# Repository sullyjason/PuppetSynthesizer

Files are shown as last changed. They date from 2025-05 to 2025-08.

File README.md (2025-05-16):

# Puppet Synth

A collaborative project between ZHdK's Departments of Interaction Design and Game Design, commissioned by Museum für Gestaltung.

## Project brief

For the Exhibition "Museum of the Future" in 2025, Zürich's Museum für Gestaltung has commissioned ZHdK to develop a series of interactive installations paying tribute to Sophie Täuber Arp's infamous wooden marionettes that she created for the play _King Stag_.

### Team

The team consists of five members coming from various disciplines.

- Lisa Bach [@julielionheart](https://github.com/julielionheart) - Unity 3D and creative direction
- Silvan Roth [@sullyjason](https://github.com/sullyjason) - Interface design and hardware
- Jan Hügli - Prototyping and production
- Jan Thürig [@JanThuering](https://github.com/JanThuering) - Unity 3D and firmware
- Jan Espig [@Jespig](https://github.com/Jespig) - Visual design
- David Bock [@davidoffcw](https://github.com/davidoffcw) & Lars Kristian [@larskristianblom](https://github.com/larskristianblom) - Sound design

## Concept

Puppet Synth is a digital reinterpretation of Sophie Taeuber-Arp’s avant-garde puppetry for King Stag, breaking with traditional visual and performative conventions. Inspired by Rudolf Laban’s choreographic notation and Taeuber-Arp’s expressive dance practice, this project brings the puppets’ gestures into the digital realm. Users are invited to choreograph puppet movements themselves. Visually, Puppet Synth renders these complex motion sequences as wave-like frequency patterns, making them both tangible and analyzable.

## Implementation

```mermaid
flowchart TD
    Interface["🎛️ Physical Interface"] --> Arduino["Analog Signal processing"]
    Arduino --> MIDI["🎹 MIDI / Control Signal"]

    MIDI --> WaveSynthesis["Wave synthesis"] --> FMOD["🔊 FMOD (Audio Synthesis)"]
    WaveSynthesis --> UnityAnim["🕺 Unity Animator (Puppet Control)"]

    FMOD --> Audio["🎵 Dynamic Audio Output"]
    UnityAnim --> Visual["🎭 Puppet Animation in Unity"]

    Audio & Visual --> Output["🎬 Final Experience (Live AV Performance)"]
```
### Interface

The interface consists of 5 types of inputs: rotary switches, smooth rotary potentiometers, linear potentiometers (faders), and momentary 3 position toggle switches.
<p align="center">
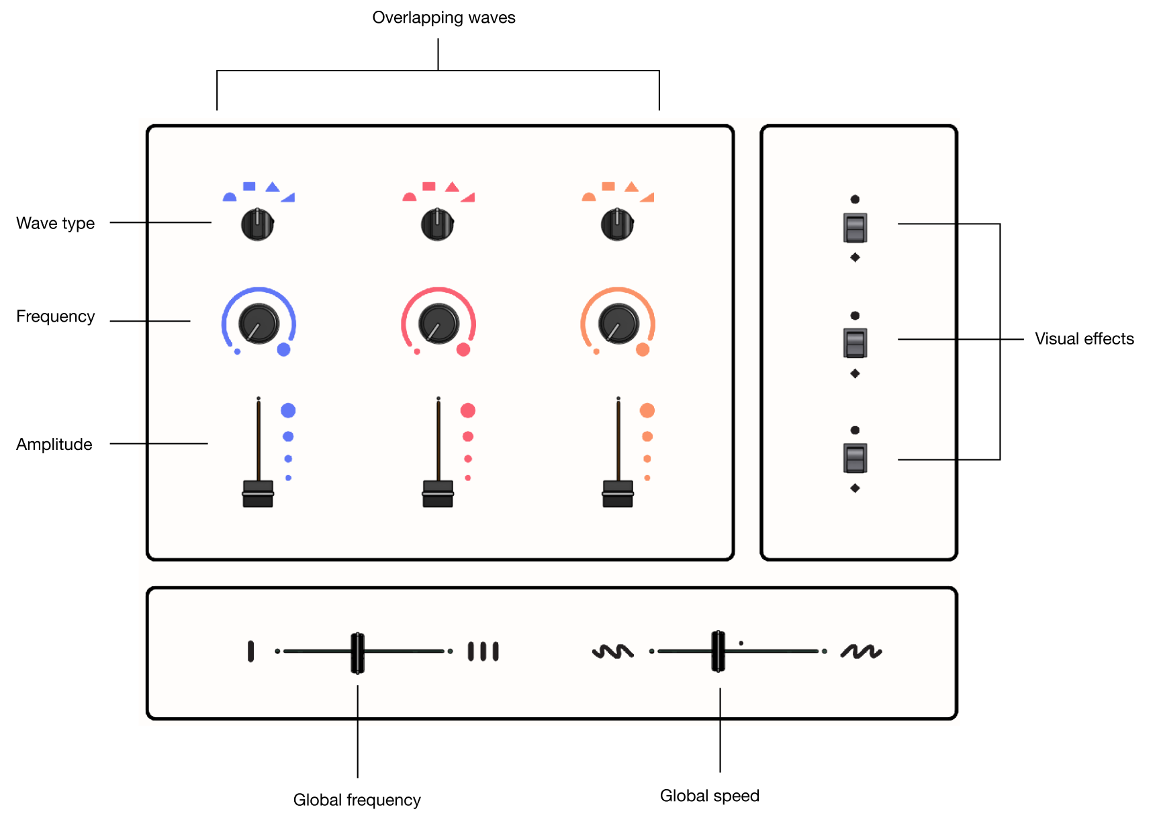
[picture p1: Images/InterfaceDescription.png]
Interface Diagram

</p>

### Visual Style

The visual style takes inspiration from Sophie Täuber-Arp's minimal color palette and simple revolved shapes that make up the marionettes.
<p align="center">
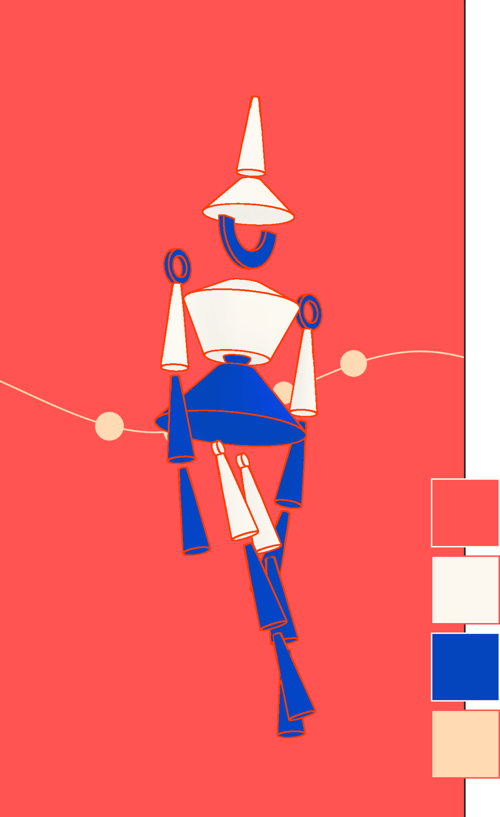
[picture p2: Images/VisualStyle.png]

</p>

## Experience

## Repository files

- Firmware (arduino code)
- Electronic Design files
- CAD drawings and STLs
- Unity build and project files
- FMOD code

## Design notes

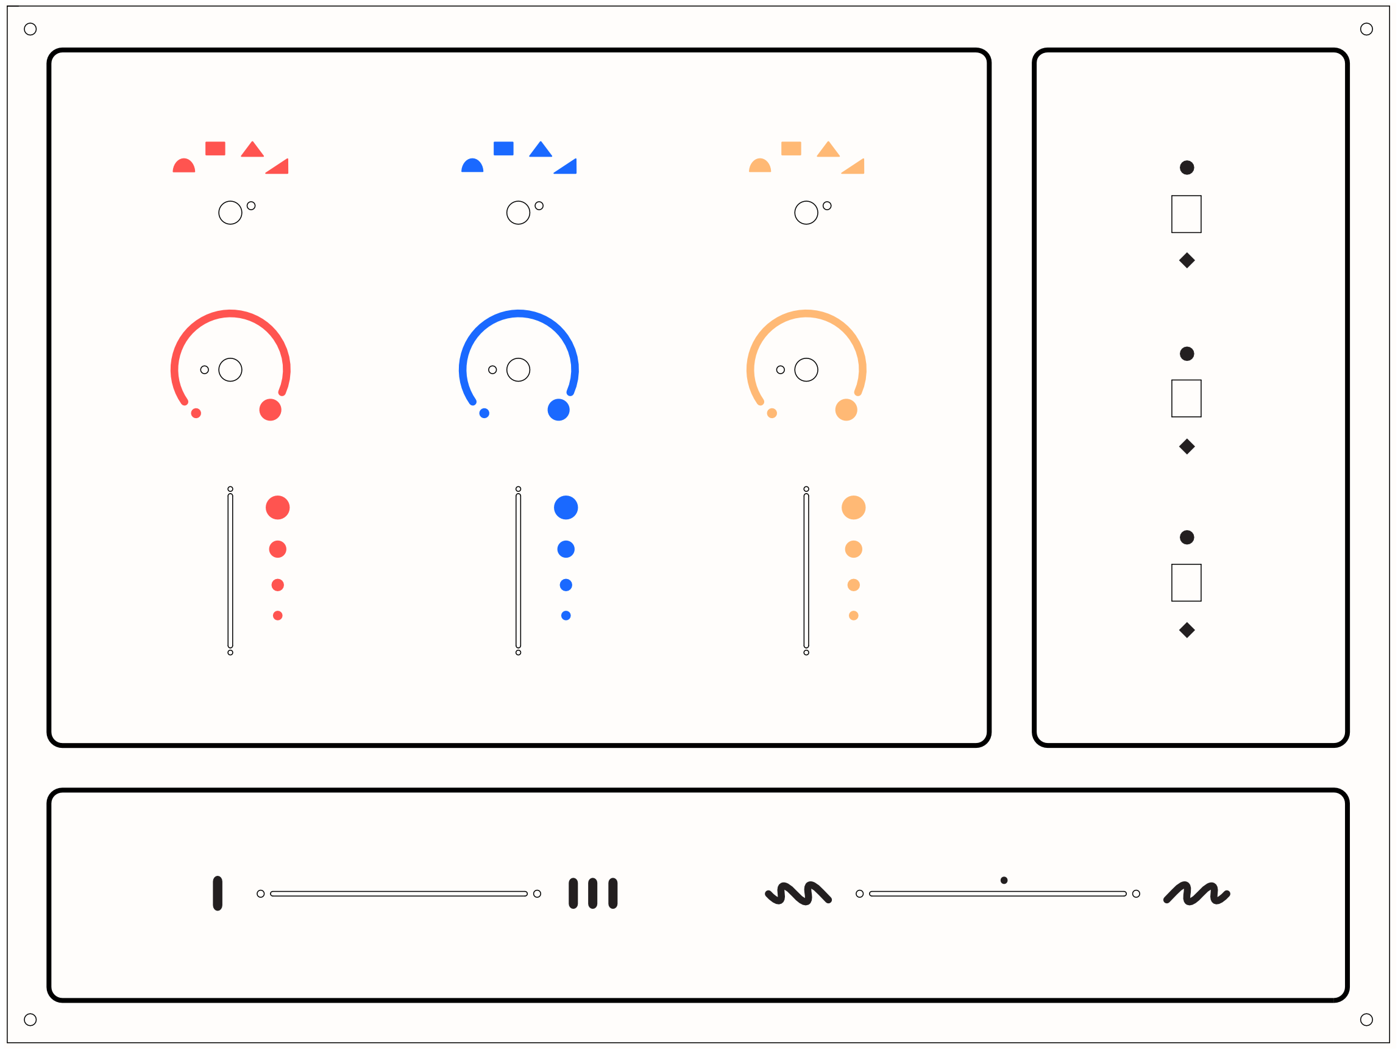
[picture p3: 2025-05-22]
Enclosure/Panel_Design.png

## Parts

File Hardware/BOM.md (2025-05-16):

# Bill of Materials (BOM)

| **Part** | **Qty** | **Link / Part Number** |
|---|---:|---|
| Rotary Switch | 3 | [DFRobot](https://www.dfrobot.com/product-970.html) |
| Linear Potentiometer 10k – 60mm travel  | 3 | [858-PS6020MC1BR10K – Mouser](https://www.mouser.ch/ProductDetail/858-PS6020MC1BR10K) |
| Linear Potentiometer 10k – 100mm travel | 2 | [858-PS1001B1BR10K – Mouser](https://www.mouser.ch/ProductDetail/858-PS1001B1BR10K) |
| Rotary Potentiometer 10k | 3 | [858-P2301FD20BR10K – Mouser](https://www.mouser.ch/ProductDetail/858-P2301FD20BR10K) |
| 3-position Rocker Switch | 3 | [506-A105J61ZQ0004 – Mouser](https://www.mouser.ch/ProductDetail/506-A105J61ZQ0004) |
| ADS1115 16-bit ADC (4-Channel) | 2 | [Adafruit #1085](https://www.adafruit.com/product/1085) |
| 2.2kΩ THT Resistor | 6 | — |
| 100Ω THT Resistor | 3 | — |
| 4.7kΩ THT Resistor | 2 | — |
| 1µF Ceramic Capacitor (THT) | 3 | — |
| Arduino Leonardo | 1 | [Arduino Docs](https://docs.arduino.cc/hardware/leonardo/) |
| Micro USB Cable – 2m | 1 | — |
| JST 2.50mm Vertical 3-pin Socket | 11 | — |
| JST 2.50mm Vertical 5-pin Socket | 6 | — |
| JST 3-pin Cable | 11 | — |
| JST 5-pin Cable | 3 | — |
| Countersunk screw M2x6 | 6 | — |
| Countersunk screw M3x6 | 4 | — |
| Countersunk screw M5x10 | 4 | — |

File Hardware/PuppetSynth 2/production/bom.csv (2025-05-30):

Designator | Footprint | Quantity | Value | LCSC Part #
10K_2 | PS6020MC1BR10K | 1 | R_Potentiometer
10K | PS1001B1BR10K | 1 | R_Potentiometer
A1 | Arduino_UNO_R3 | 1 | Arduino_Leonardo
C3, C4, C5 | C_Disc_D3.0mm_W2.0mm_P2.50mm | 3 | 1uF
H1, H13, H2, H3, H4 | MountingHole_3.2mm_M3 | 5 | MountingHole_M3
J10, J19, J8, J9 | PinSocket_1x06_P2.54mm_Vertical | 4 | PINHD_1x6_Female
J11, J12, J16, J20, J24, J25, J26, J3 | JST_EH_B3B-EH-A_1x03_P2.50mm_Vertical | 8 | JST_03
J13, J14, J15, J5 | JST_EH_B5B-EH-A_1x05_P2.50mm_Vertical | 4 | JST_05
JP1, JP2 | SolderJumper-2_P1.3mm_Open_RoundedPad1.0x1.5mm | 2 | Jumper_2_Bridged
R1, R2 | R_Axial_DIN0207_L6.3mm_D2.5mm_P10.16mm_Horizontal | 2 | 4.7k
R10, R11, R13, R14, R4, R5 | R_Axial_DIN0207_L6.3mm_D2.5mm_P10.16mm_Horizontal | 6 | 2.2k
R12, R17, R9 | R_Axial_DIN0207_L6.3mm_D2.5mm_P10.16mm_Horizontal | 3 | 100ohm

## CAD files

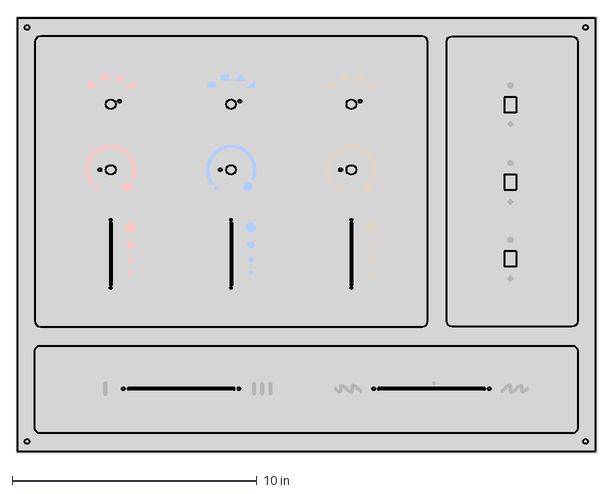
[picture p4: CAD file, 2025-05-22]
Enclosure/Panel_Design.dxf
23.8 x 17.9 in

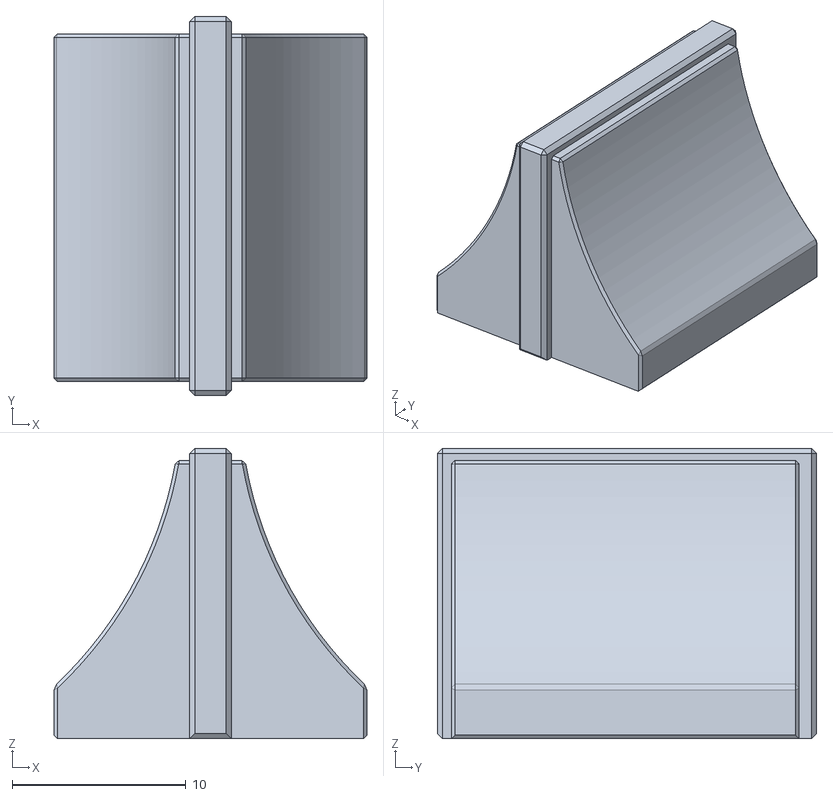
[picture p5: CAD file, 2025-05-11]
Hardware/Components/Caps/small faders.stl
18.0 x 21.8 x 16.7

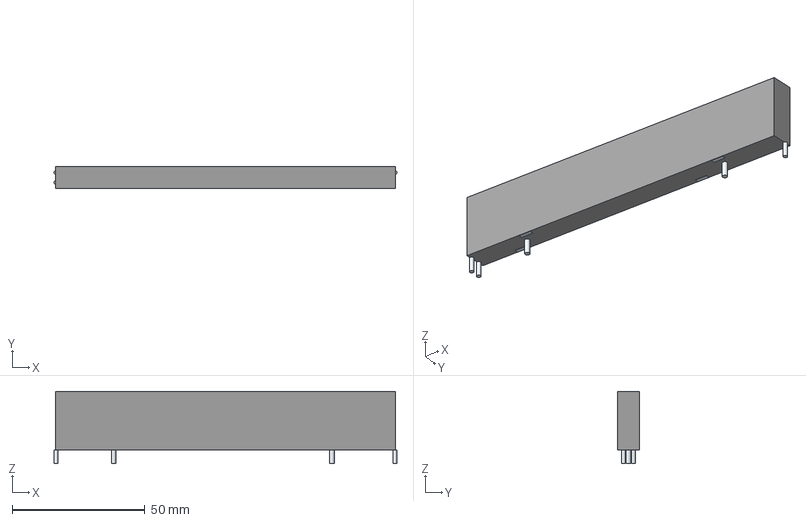
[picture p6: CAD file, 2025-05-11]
Hardware/Components/Fader_Long/PS100-1B1BR10K.stp
129.1 x 8.40 x 27.1 mm
Pins
Leads

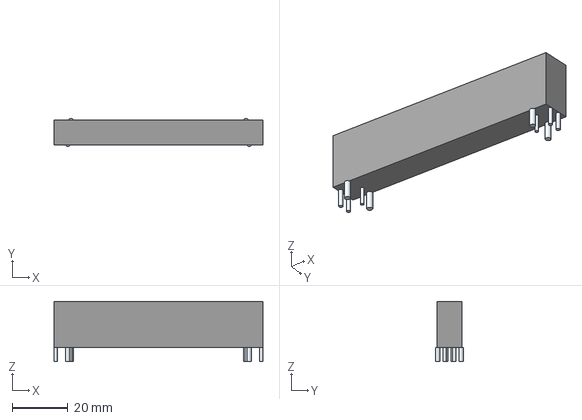
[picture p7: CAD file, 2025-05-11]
Hardware/Components/Fader_Short/PS60-20MC1BR10K.stp
75.0 x 10.2 x 21.6 mm
Leads x 10

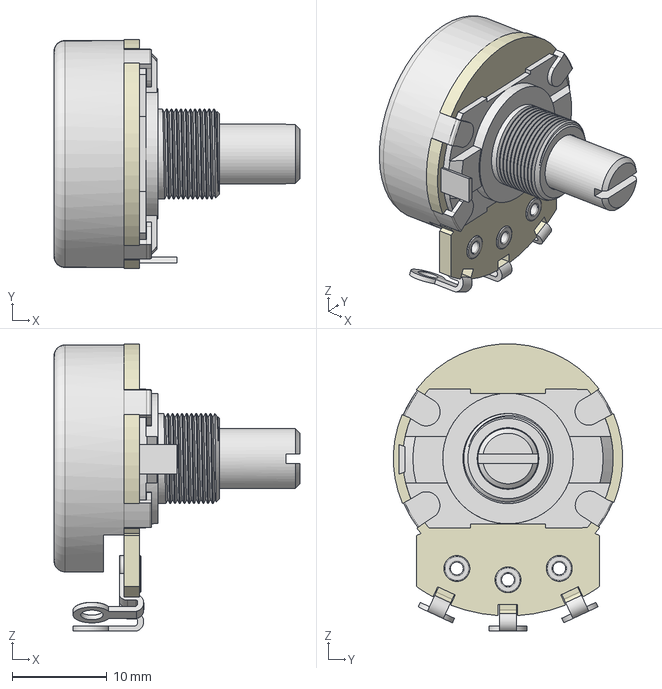
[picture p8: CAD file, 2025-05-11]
Hardware/Components/Potentiometer/P230-1EC15AR1MEG.stp
26.0 x 24.2 x 30.3 mm

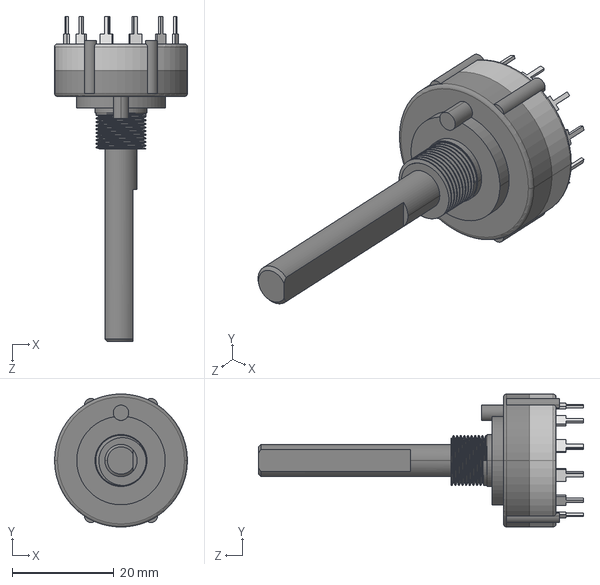
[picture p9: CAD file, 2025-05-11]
Hardware/Components/Rotary_Switch/CK1056.stp
26.2 x 26.2 x 64.1 mm

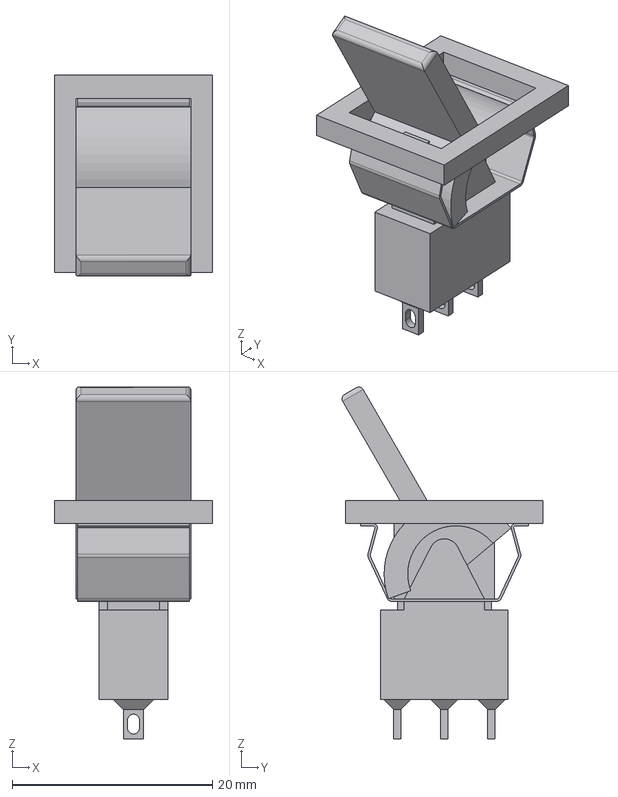
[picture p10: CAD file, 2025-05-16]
Hardware/Components/Toggle/A105J61ZQ0004.stp
15.8 x 20.1 x 35.1 mm

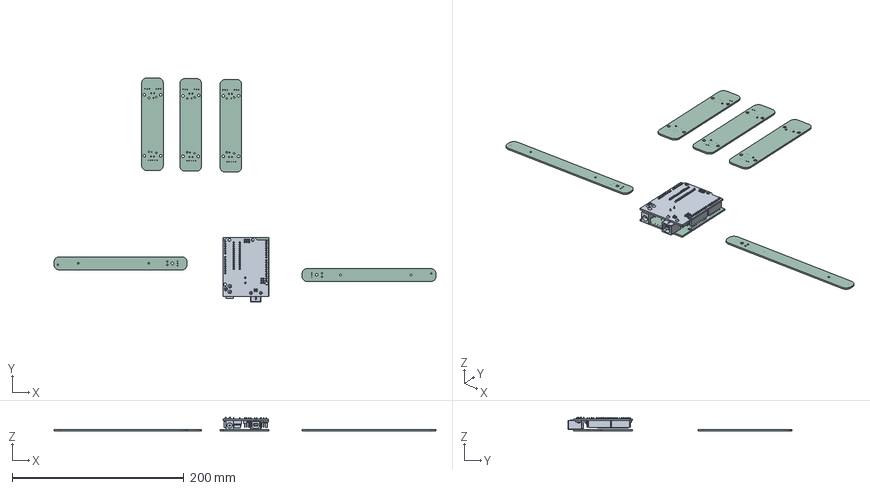
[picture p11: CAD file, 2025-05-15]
Hardware/PuppetSynth 2/PuppetSynth_v2_PCB.step
445.2 x 261.3 x 16.5 mm
ARDUINO-UNO
_autosave-PuppetSynth_v2_PCB_PCB_1
_autosave-PuppetSynth_v2_PCB_PCB_2
_autosave-PuppetSynth_v2_PCB_PCB_3
_autosave-PuppetSynth_v2_PCB_PCB_4
_autosave-PuppetSynth_v2_PCB_PCB_5
_autosave-PuppetSynth_v2_PCB_PCB_6
_autosave-PuppetSynth_v2_PCB_PCB_7
_autosave-PuppetSynth_v2_PCB_PCB_8
_autosave-PuppetSynth_v2_PCB_PCB_9
_autosave-PuppetSynth_v2_PCB_PCB_10
_autosave-PuppetSynth_v2_PCB_PCB_11
_autosave-PuppetSynth_v2_PCB_PCB_12
_autosave-PuppetSynth_v2_PCB_PCB_13
_autosave-PuppetSynth_v2_PCB_PCB_14
_autosave-PuppetSynth_v2_PCB_PCB_15
_autosave-PuppetSynth_v2_PCB_PCB_16
_autosave-PuppetSynth_v2_PCB_PCB_17
_autosave-PuppetSynth_v2_PCB_PCB_18
_autosave-PuppetSynth_v2_PCB_PCB_19
_autosave-PuppetSynth_v2_PCB_PCB_20
_autosave-PuppetSynth_v2_PCB_PCB_21
_autosave-PuppetSynth_v2_PCB_PCB_22
_autosave-PuppetSynth_v2_PCB_PCB_23
_autosave-PuppetSynth_v2_PCB_PCB_24
_autosave-PuppetSynth_v2_PCB_PCB_25
_autosave-PuppetSynth_v2_PCB_PCB_26
_autosave-PuppetSynth_v2_PCB_PCB_27
_autosave-PuppetSynth_v2_PCB_PCB_28
_autosave-PuppetSynth_v2_PCB_PCB_29
_autosave-PuppetSynth_v2_PCB_PCB_30
_autosave-PuppetSynth_v2_PCB_PCB_31
_autosave-PuppetSynth_v2_PCB_PCB_32
_autosave-PuppetSynth_v2_PCB_PCB_33
_autosave-PuppetSynth_v2_PCB_PCB_34
_autosave-PuppetSynth_v2_PCB_PCB_35
_autosave-PuppetSynth_v2_PCB_PCB_36

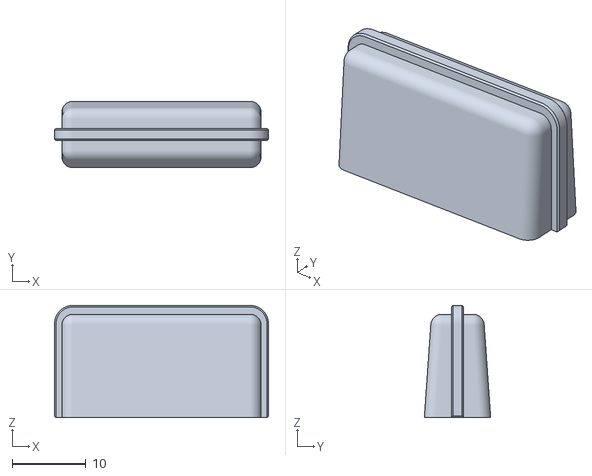
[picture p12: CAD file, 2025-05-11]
Hardware/Components/Caps/Large faders.stl
29.0 x 9.00 x 15.2

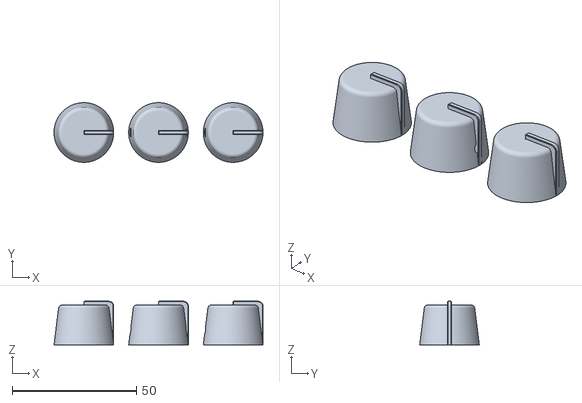
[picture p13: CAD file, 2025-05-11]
Hardware/Components/Caps/knobs.stl
84.0 x 24.0 x 17.5

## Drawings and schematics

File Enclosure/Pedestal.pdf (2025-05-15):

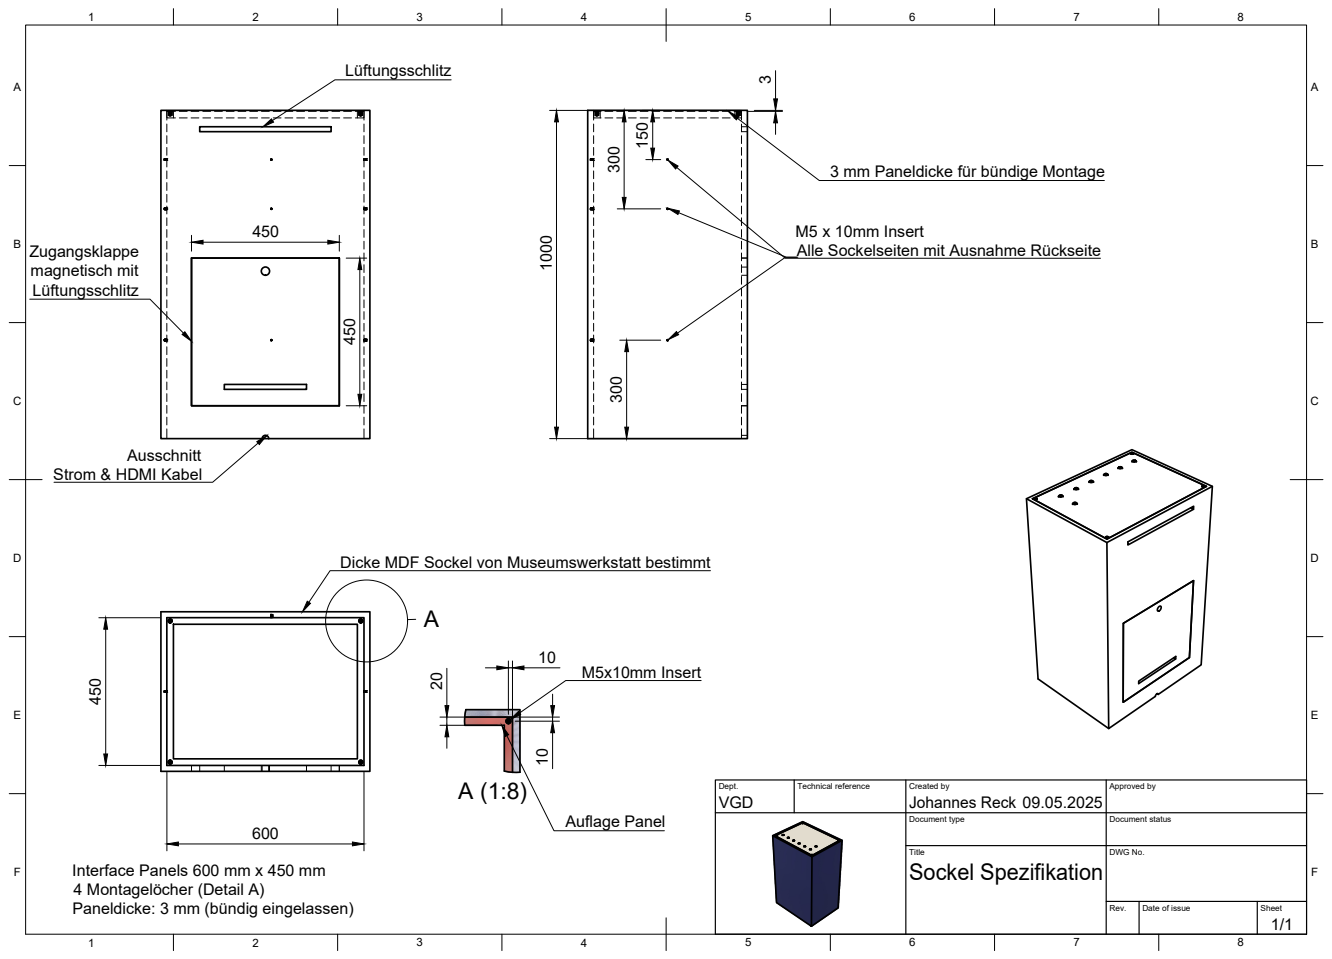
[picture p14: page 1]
Title; DWG No.; Rev.; Date of issue; Sheet; Sockel Spezifikation; M5x10mm Insert; M5 x 10mm Insert; magnetisch mit; Auflage Panel

Alle Sockelseiten mit Ausnahme Rückseite 150 300 300

3 mm Paneldicke für bündige Montage

Strom & HDMI Kabel

Dicke MDF Sockel von Museumswerkstatt bestimmt

Dept. VGD | Technical reference | Created by Johannes Reck 09.05.2025 | Approved by

Document type | Document status

Interface Panels 600 mm x 450 mm
4 Montagelöcher (Detail A)
Paneldicke: 3 mm (bündig eingelassen)

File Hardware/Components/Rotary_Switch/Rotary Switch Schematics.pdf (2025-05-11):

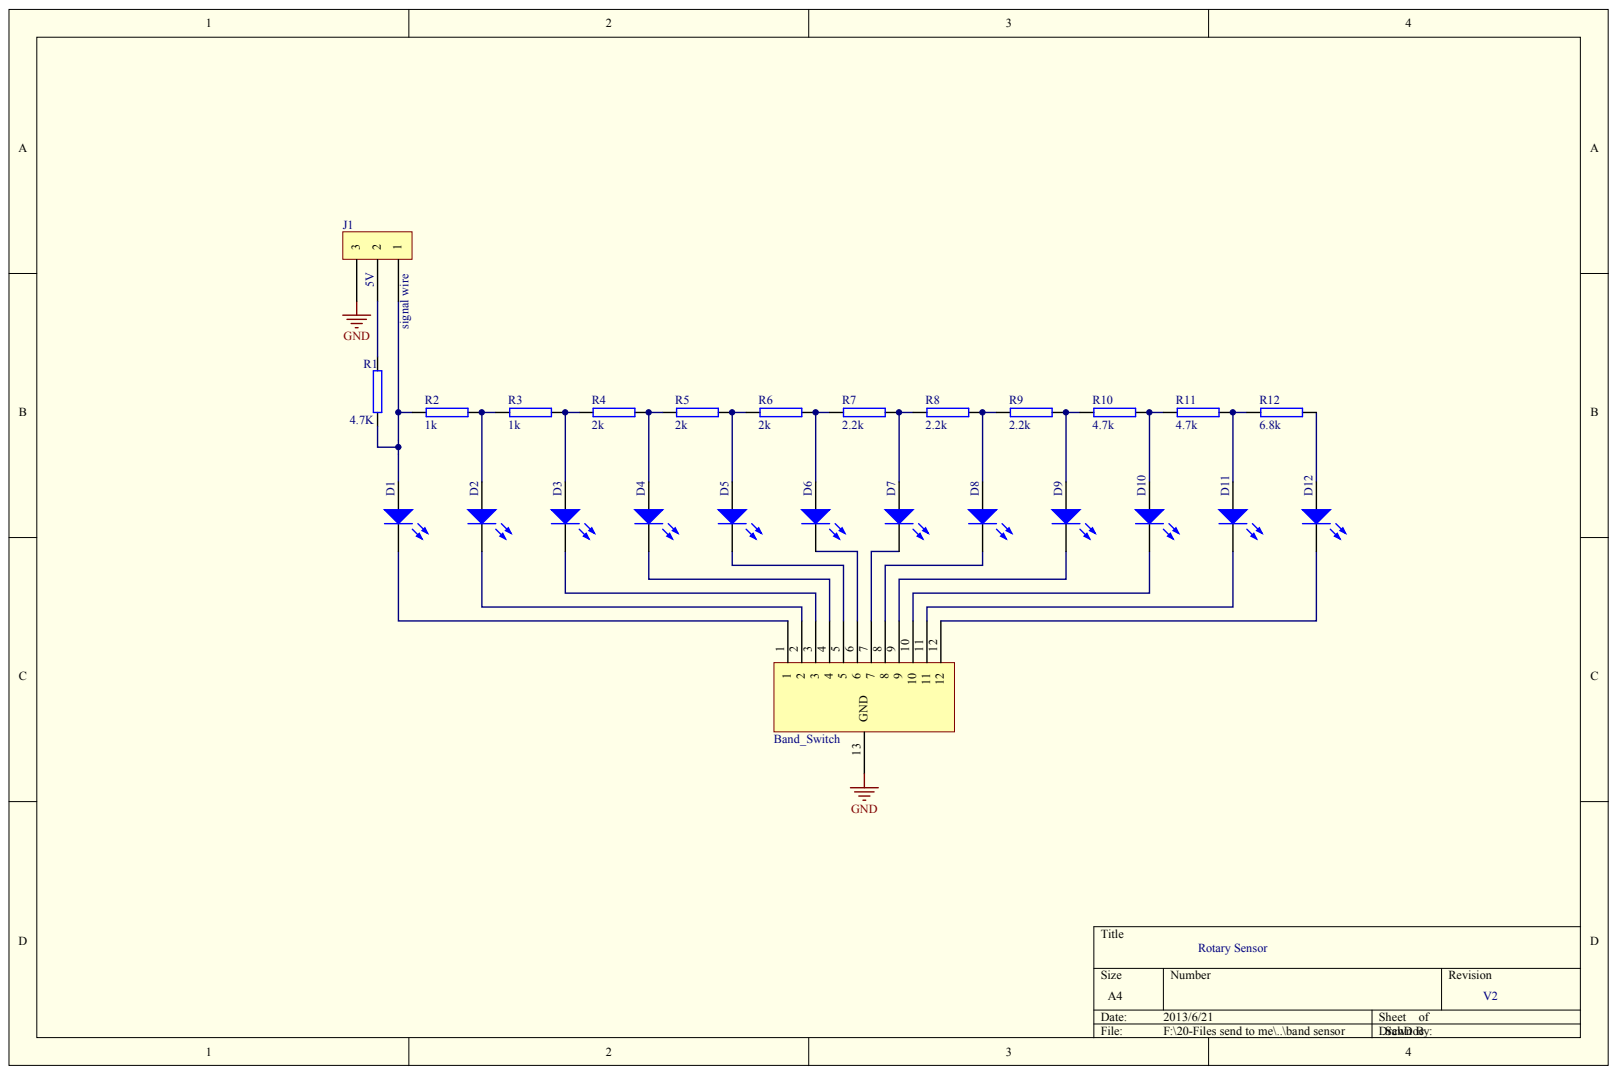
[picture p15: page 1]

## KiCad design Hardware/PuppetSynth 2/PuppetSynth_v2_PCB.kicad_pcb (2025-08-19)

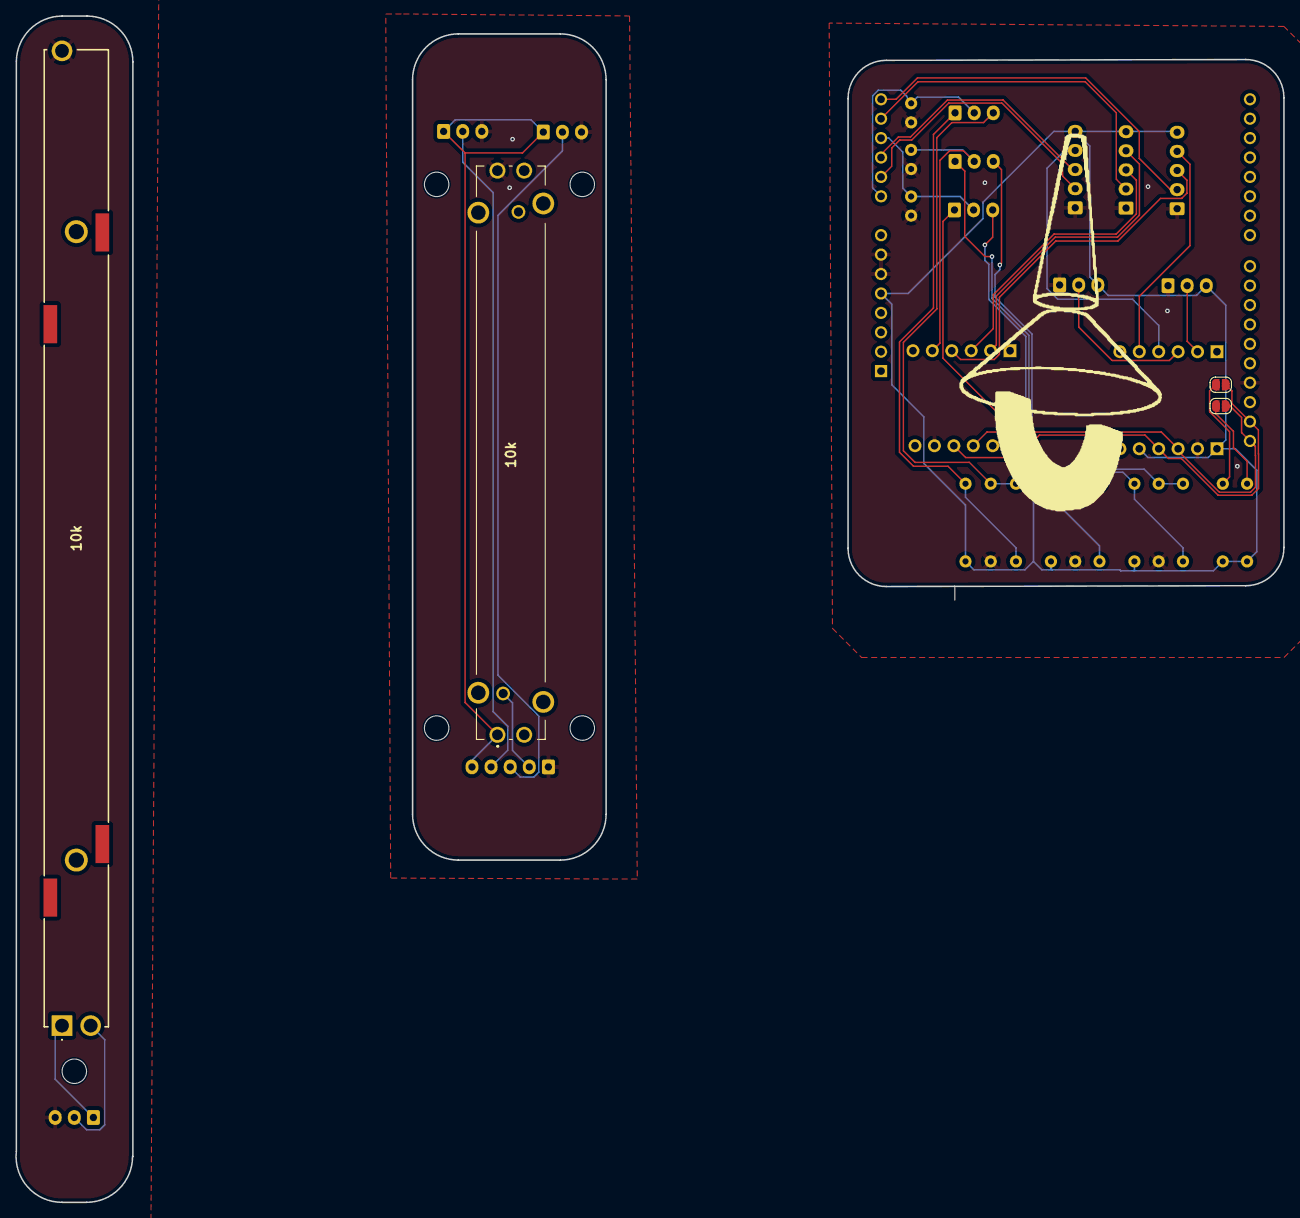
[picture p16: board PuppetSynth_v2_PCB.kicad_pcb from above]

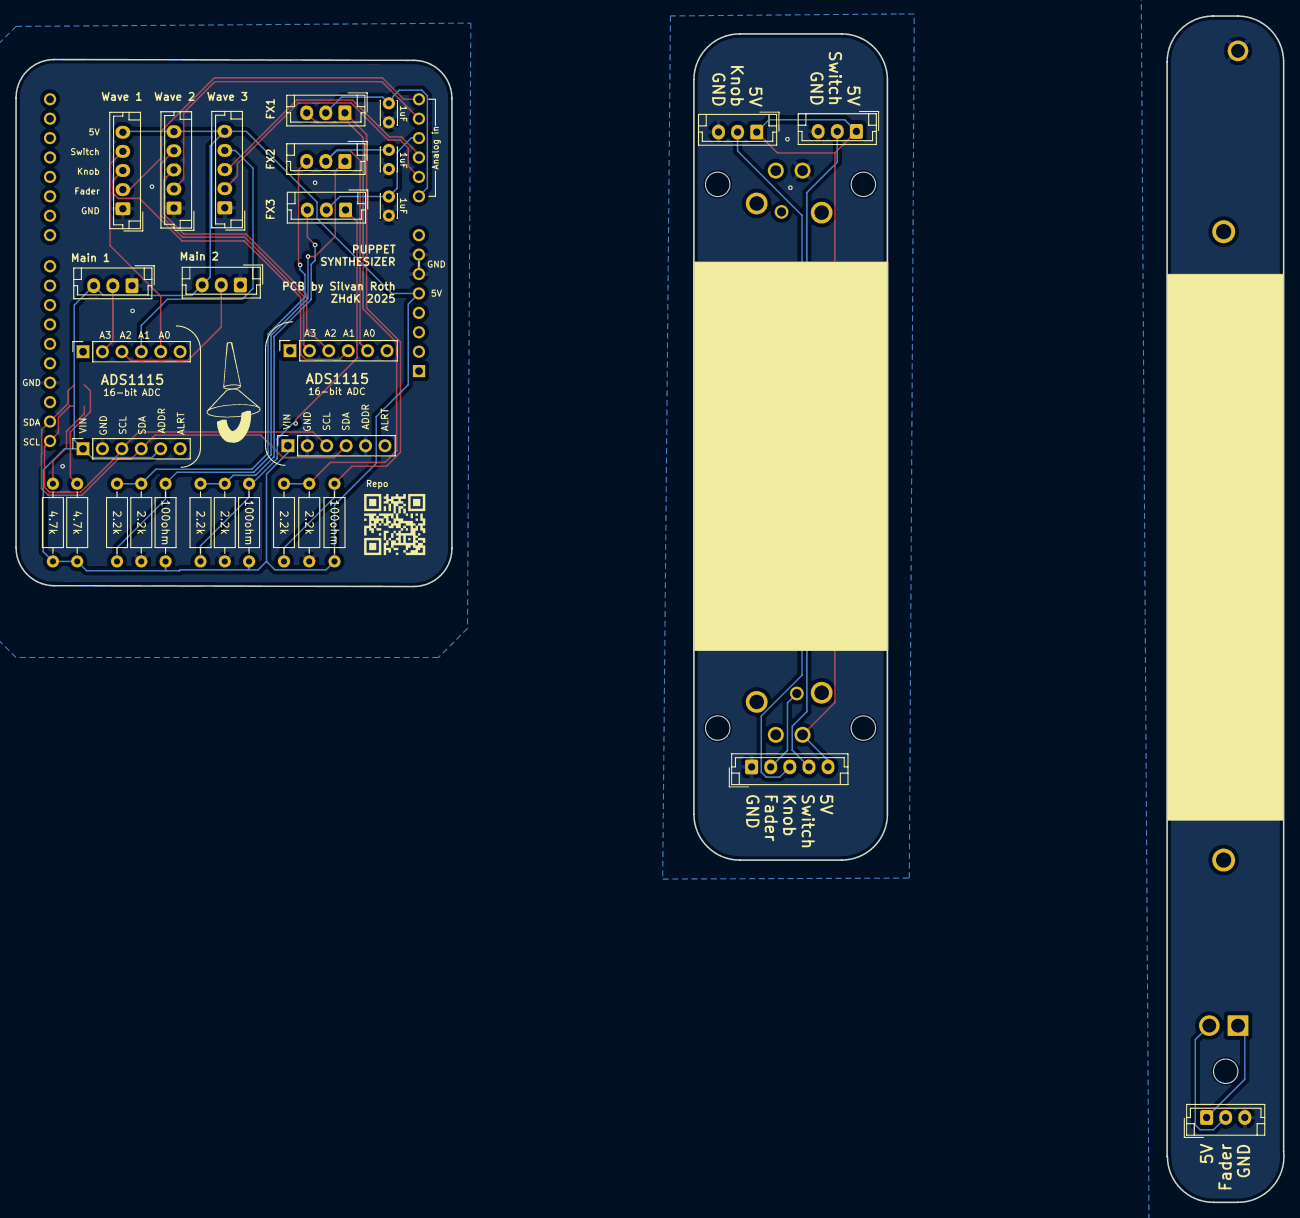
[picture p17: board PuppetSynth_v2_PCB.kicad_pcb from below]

Board: 2 copper layers, 57.0 x 68.9 mm, 40 parts (30 on the bottom side), 26 nets.

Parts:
10k: R_Potentiometer; PS6020MC1BR10K
10k#2: R_Potentiometer; PS1001B1BR10K
A1: Arduino_Leonardo; Arduino_UNO_R3
C3, C4, C5: 1uF; C_Disc_D3.0mm_W2.0mm_P2.50mm
H1, H2, H3, H4, H13: MountingHole_M3; MountingHole_3.2mm_M3
J3, J11, J12, J16, J20, J24, J25, J26: JST_03; JST_EH_B3B-EH-A_1x03_P2.50mm_Vertical
J5, J13, J14, J15: JST_05; JST_EH_B5B-EH-A_1x05_P2.50mm_Vertical
J8, J9, J10, J19: PINHD_1x6_Female; PinSocket_1x06_P2.54mm_Vertical
JP1, JP2: Jumper_2_Bridged; SolderJumper-2_P1.3mm_Open_RoundedPad1.0x1.5mm
R1, R2: 4.7k; R_Axial_DIN0207_L6.3mm_D2.5mm_P10.16mm_Horizontal
R4, R5, R10, R11, R13, R14: 2.2k; R_Axial_DIN0207_L6.3mm_D2.5mm_P10.16mm_Horizontal
R9, R12, R17: 100ohm; R_Axial_DIN0207_L6.3mm_D2.5mm_P10.16mm_Horizontal

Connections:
+5V: 10k.1, 10k#2.1, A1.5 (+5V), J3.1, J5.5, J8.1, J10.1, J10.5, J11.3, J12.3, J13.5, J14.5, J15.5, J16.1, J20.1, R1.2, R2.2, R9.2, R12.2, R17.2
GND: 10k.3, 10k#2.3, A1.6 (GND), A1.7 (GND), A1.29 (GND), C3.2, C4.2, C5.2, J3.3, J5.1, J8.2, J8.5, J10.2, J11.1, J12.1, J13.1, J14.1, J15.1, J16.3, J20.3, R5.1, R10.1, R13.1
Knob_1: J5.3, J9.4, J13.3, J20.2
Knob_2: J9.3, J14.3
Knob_3: A1.11 (A2), J15.3
Main_1: 10k#2.2, J3.2, J11.2, J19.2
Main_2: J12.2, J19.3
unnamed: C3.1, J24.2
unnamed: J24.1, R4.2, R9.1
unnamed: J24.3, R4.1, R5.2
unnamed: J25.1, R11.2, R12.1
unnamed: J25.3, R10.2, R11.1
unnamed: J26.1, R14.2, R17.1
unnamed: J26.3, R13.2, R14.1
unnamed: JP1.1 (A), R1.1
unnamed: JP2.1 (A), R2.1
SCL: A1.32 (SCL/D3), J8.3, J10.3, JP1.2 (B)
SDA: A1.31 (SDA/D2), J8.4, J10.4, JP2.2 (B)
Small_Fader_1: 10k.2, A1.14 (A5), J5.2, J13.2
Small_Fader_2: A1.13 (A4), J14.2
Small_Fader_3: A1.10 (A1), J15.2
Switch_1: J5.4, J13.4, J16.2, J19.5
Switch_2: J9.2, J14.4
Switch_3: J15.4, J19.4
Toggle_2: C4.1, J9.5, J25.2
Toggle_3: A1.12 (A3), C5.1, J26.2

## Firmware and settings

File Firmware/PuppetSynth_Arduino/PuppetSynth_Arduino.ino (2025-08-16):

/*
TODO:
- Check mapping accuracy and direction
- make sure to reach max and min
- connect resistors to rotary switches to turn into potentiometers
- map rotary switches correctly
- toggle debugging mode
*/

//toggle debug mode-----------------------------------------------------------------------------------------------------

#define DEBUG 0


//libraries-------------------------------------------------------------------------------------------------------------

#include <Wire.h>
#include <Adafruit_ADS1X15.h>
#include <MIDIUSB.h>

Adafruit_ADS1115 analogBoard1;    // First ADS1115 at address 0x48
Adafruit_ADS1115 analogBoard2;    // Second ADS1115 at address 0x49

//output ranges---------------------------------------------------------------------------------------------------------

#define OUT_MIN 0               // MIDI range minimum
#define OUT_MAX 127             // MIDI range maximum  
#define defineThreshHold 1      //Threshhold for checking for changes in MIDI values


//input leonardo
// ---------------------------------------------------------------------------------------------------------

struct InputMapping {
    int inputNumber;            // The index of the input
    const char* functionName;   // What the input does
    int pinNumber;              // The pin number
    int readSignal;             // The signal received by the Arduino
    int inMin;                  // Input range minimum
    int inMax;                  // Input range maximum
    int outMin;                 // Output range minimum
    int outMax;                 // Output range maximum
    int mappedSignal;           // The mapped signal to send to MIDI
    int midiChannel;            // MIDI Channel number ("control" in helper function)
};


// The following values need to be modified if any changes are made to the hardware. Currently configured with 2 ADS1115s, called analogBoard1 and analogBoard2.
// The remaining analog inputs are connected to the Arduino directly.

InputMapping leonardo [] = {

  //  Index   functionName       pinNumber   readSignal  inMin, inMax    outMin, outMax  	mappedSignal    midiChannel
  // -----------------------------------------------------------------------------------------------------------------------
      {0,      "EMPTY",			      0,			      0,		    0,  0,			  OUT_MIN, OUT_MAX,        0,				0		  	},
      {1,      "FREQ_3",			    A2,			      0,		    0, 1023, 	    OUT_MIN, OUT_MAX,	       0,				12			}, 
      {2,      "AMP_1",			      A5,			      0,		    15, 1000,	    OUT_MIN, OUT_MAX,	       0,				1		  	},
      {3,     "AMP_2",			      A4,			      0,		    15, 1000,	    OUT_MIN, OUT_MAX,	       0,				2		  	},
      {4,     "AMP_3",			      A1,			      0,		    15, 1000,	    OUT_MIN, OUT_MAX,	       0,				3		  	},
      {5,     "EFFECT_1",		      A0,			      0,		    1023, 510,		OUT_MIN, OUT_MAX,	       0,				32			},
      {6,     "EFFECT_3",		      A3,			      0,		    1023, 510,		OUT_MIN, OUT_MAX,	       0,				34			},
};		

InputMapping ads1[] = {
    //  Index   functionName       pinNumber   readSignal  inMin, inMax    outMin, outMax  	mappedSignal    midiChannel
    // -----------------------------------------------------------------------------------------------------------------------
        {0,      "EFFECT_2",			  0,		    	0,		    	4400, 32700,	  OUT_MIN, OUT_MAX,   0,				33      },
        {1,      "WAVE_TYPE_2",		  3,  	    	0,		    	20200, 29800,	  OUT_MIN, OUT_MAX,	  0,				16			},
        {2,      "FREQ_1",			    2,		    	0,		    	-10, 33000,		  OUT_MIN, OUT_MAX,	  0,				10			},
        {3,      "FREQ_2",			    1,		    	0,		    	-10, 33000,	  	OUT_MIN, OUT_MAX,	  0,				11			},
};	

InputMapping ads2[] = {
    //  Index   functionName       pinNumber   readSignal  inMin, inMax    outMin, outMax  	mappedSignal    midiChannel
    // -----------------------------------------------------------------------------------------------------------------------
    {0,      "EMPTY",			          0,		    	0,		    	0,  0,			    OUT_MIN, OUT_MAX,   0,			  0			  },
    {1,      "MAIN_SPEED",		      2,		    	0,		    	0, 32000,		    OUT_MIN, OUT_MAX,	  0,				9			  },  
    {2,      "MAIN_FREQ",		        3,		    	0,		    	60, 32000,		  OUT_MIN, OUT_MAX,	  0,				8			  },  
    {3,      "WAVE_TYPE_1",		      0,		    	0,		    	20200, 29900,	  OUT_MIN, OUT_MAX,	  0,				15			},  
    {4,      "WAVE_TYPE_3",		      1,		    	0,		    	20200,29900,	  OUT_MIN, OUT_MAX,	  0,				17			},  
};


// Move these to global scope so they persist between loop iterations
int lastMappedSignalsLeonardo[7] = {0};
int lastMappedSignalsAds1[4] = {0};
int lastMappedSignalsAds2[5] = {0};

void setup(){
    Serial.begin(9600);
    Wire.begin(); // Initialize I2C communication
    Wire.setClock(400000); // Set I2C clock speed to 400kHz (optional)
  
    // Enable internal pull-up resistors on SDA and SCL
    // digitalWrite(SDA, HIGH);
    //digitalWrite(SCL, HIGH);
  
    // Initialize the first ADS1115 (address 0x48)
    if (!analogBoard1.begin(0x48)) {
      Serial.println("Failed to initialize analogBoard1115 at address 0x48.");
      while (1);
    }
  
    // Initialize the second ADS1115 (address 0x49)
    if (!analogBoard2.begin(0x49)) {
      Serial.println("Failed to initialize ADS1115 at address 0x49.");
      while (1);
    }
  
    // Set the gain (optional, default is +/- 4.096V)
    analogBoard1.setGain(GAIN_ONE); // +/- 4.096V
    analogBoard2.setGain(GAIN_ONE); // +/- 4.096V
}

void loop(){

  ReadInputs();
  MapInValues();

  DetectChange(leonardo, 7, lastMappedSignalsLeonardo);
  DetectChange(ads1, 4, lastMappedSignalsAds1);
  Serial.println(ads1[0].readSignal);
  DetectChange(ads2, 5, lastMappedSignalsAds2);
    
  //Ensure all Midi messages are sent
  MidiUSB.flush();
}

// -------------------- MIDI HELPER ------------------------

void sendMIDIControlChange(byte control, byte value) {
    // CC on Channel 1 => 0xB0
    midiEventPacket_t event = {0x0B, 0xB0, control, value};
    MidiUSB.sendMIDI(event);
}

void ReadInputs()
{
  // Read all inputs first, then process them
  //read the main faders:
  ads2[1].readSignal = analogBoard2.readADC_SingleEnded(ads2[1].pinNumber);
  ads2[2].readSignal = analogBoard2.readADC_SingleEnded(ads2[2].pinNumber);

  //read the wavetype knobs:
  ads2[3].readSignal = analogBoard2.readADC_SingleEnded(ads2[3].pinNumber);
  ads1[1].readSignal = analogBoard1.readADC_SingleEnded(ads1[1].pinNumber);
  ads2[4].readSignal = analogBoard2.readADC_SingleEnded(ads2[4].pinNumber);

  //read the frequency knobs:
  ads1[2].readSignal = analogBoard1.readADC_SingleEnded(ads1[2].pinNumber);
  ads1[3].readSignal = analogBoard1.readADC_SingleEnded(ads1[3].pinNumber);
  leonardo[1].readSignal = analogRead(leonardo[1].pinNumber);

  //read the amps:
  leonardo[2].readSignal = analogRead(leonardo[2].pinNumber);
  leonardo[3].readSignal = analogRead(leonardo[3].pinNumber);
  leonardo[4].readSignal = analogRead(leonardo[4].pinNumber);

  //read the effects:
  leonardo[5].readSignal = analogRead(leonardo[5].pinNumber);
  leonardo[6].readSignal = analogRead(leonardo[6].pinNumber);
  ads1[0].readSignal = analogBoard1.readADC_SingleEnded(ads1[0].pinNumber);
}

void MapInValues()  //it works here
{
    //maps signal between inMin - inMax (not 0-127)

    //LEONARDO
    for(int i = 0; i < 7; i++){
      if(i<5)
      {
        leonardo[i].mappedSignal = map(leonardo[i].readSignal, leonardo[i].inMin, leonardo[i].inMax, leonardo[i].outMin, leonardo[i].outMax);
      }else{
        if(leonardo[i].readSignal < 500)  //default
        {
          leonardo[i].mappedSignal = 0;
        }else if(leonardo[i].readSignal > 500 && leonardo[i].readSignal < 1000)
        {
          leonardo[i].mappedSignal = 64;
        }else{
          leonardo[i].mappedSignal = 127;
        }

      }

    }

    //ADS 1
    for(int i = 0; i < 4; i++){
        if(i == 0)
        {
          if(ads1[i].readSignal < 5000)  //default
          {
            ads1[i].mappedSignal = 64;
          }
          else if(ads1[i].readSignal > 5000 && ads1[i].readSignal < 25000)
          {
            ads1[i].mappedSignal = 0;
          }else{
            ads1[i].mappedSignal = 127;
          }
          
        }else if(i == 2 || i == 3)
        { 
          ads1[i].mappedSignal = -map(ads1[i].readSignal, ads1[i].inMin, ads1[i].inMax, ads1[i].outMin, ads1[i].outMax);
        }
        else{

          ads1[i].mappedSignal = map(ads1[i].readSignal, ads1[i].inMin, ads1[i].inMax, ads1[i].outMin, ads1[i].outMax);
          
        }
    }

    //ADS 2
    for(int i = 0; i < 5; i++){
      ads2[i].mappedSignal = map(ads2[i].readSignal, ads2[i].inMin, ads2[i].inMax, ads2[i].outMin, ads2[i].outMax);
    }
}

void DetectChange(InputMapping * array, int arrayLength, int lastArray[])
{
  for(int i = 0; i < arrayLength; i++){ 
    if(abs(lastArray[i] - array[i].mappedSignal) > defineThreshHold) 
    {

      //Update last values AFTER comparison
      lastArray[i] = array[i].mappedSignal;

      //constrain mappedSignal between 0-127
      array[i].mappedSignal = constrain(array[i].mappedSignal, 0, 127);

      //Send MIDI event
      sendMIDIControlChange(array[i].midiChannel, array[i].mappedSignal);

    }
  }
}

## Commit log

2025-03-06 Initial push
    [PuppetSynth.kicad_pcb, PuppetSynth.kicad_sch, PuppetSynth_v2.kicad_sch]
2025-03-06 Added arduino libraries
2025-03-06 updated and exported schematic
    [PuppetSynth.kicad_sch]
2025-03-09 edit firmware
    [PuppetSynth.kicad_sch]
2025-05-09 Updated code for prototype v2 and updated schematic
    [PuppetSynth_v2.kicad_pcb, PuppetSynth_v2.kicad_sch, PuppetSynth_v2_PCB.kicad_pcb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]
2025-05-11 Updated PCBs, Archived 3D models, deleted old schematic
    [PuppetSynth.kicad_pcb, PuppetSynth_v2_PCB.kicad_pcb, PuppetSynth_v2_PCB.kicad_sch]
2025-05-11 Added component files
    [CK1056.stp, Large faders.stl, P230-1EC15AR1MEG.stp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]
2025-05-15 updated pcb
    [PuppetSynth_v2_PCB.kicad_pcb, PuppetSynth_v2_PCB.kicad_sch, PuppetSynth_v2_PCB.step]
2025-05-16 organized folders, added missing files
    [A105J61ZQ0004.stp]
2025-05-18 updated PCB: Rounded traces and shield edges
    [PuppetSynth_v2_PCB.kicad_pcb]
2025-05-22 Added panel designs, updated readme images
    [Panel_Design.dxf]
2025-05-30 Updated schematic and PCB
    fixed symbols in schematic, rearranged some parts on PCB, ran traces, aesthetic improvements, fixed layers
    [PuppetSynth_v2_PCB.kicad_pcb, PuppetSynth_v2_PCB.kicad_sch, bom.csv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]
2025-08-16 Updates pre exhbition
    [PuppetSynth.kicad_sch, PuppetSynth_v2.kicad_pcb, PuppetSynth_v2.kicad_sch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]
2025-08-17 minor fixes
    [PuppetSynth_v2_PCB.kicad_pcb]
2025-08-19 PCB fixes
    [PuppetSynth_v2_PCB.kicad_pcb]
